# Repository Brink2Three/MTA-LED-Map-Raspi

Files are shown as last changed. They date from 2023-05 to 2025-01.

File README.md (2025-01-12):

# MTA-LED-Map-Raspi

## IN PROGRESS

A single python file that will pull NYC-MTA GTFS data and assign it to individually addressable LEDs. May also include NJ PATH data if I ever figure out how to parse their API.

## To make this yourself

### Parts

- Raspberry Pi (I have tested with a Zero1 W and a Zero 2 W)
- a 5V 8A Power supply (Enough to power the entire board you connect)
- Dupont connectors (for connecting power supply to board/Raspi for now)
- A board, ordered from JCLPCB, PCBway or any PCB order vendor. (see Maps/PCB Gerber Files)

### Software Steps

Install python3. This was tested on windows 10 22H2 with Python 3.10 and on a raspberry Pi Zero2 with Python 3.9.2.
Only the requests testing will work on windows, as the LED code will attempt to connect to non-existent GPIO pins.
//TODO Make "test display" via console to display labeled stops with LED colors.

Install the following dependancies as root. As far as I know, you cannot install them in a virtual environment. They need root access to use the GPIO pins.

```bash
sudo pip install rpi_ws281x
sudo pip install adafruit-circuitpython-neopixel
sudo python3 -m pip install --force-reinstall adafruit-blinka
sudo pip install time
sudo pip install datetime
sudo pip install nyct_gtfs
```

(python-dotenv used to be required, but nyct_gtfs no longer requires API keys!)

You can ignore warnings about any scripts not being in PATH.

Clone this repo to the raspberry pi, running raspbian 11 (raspberry piOS lite) or ubuntu server. The exact version I am running is `Raspbian GNU/Linux 11 (bullseye)`

Depending on what boards you have connected, run the related "displaymode.py" script.
*THIS WILL TAKE A MINUTE TO UPDATE.*
The raspberry pi Zero 1 is SLOW to read the SD card, and takes about 45-75 seconds per cycle.
The Pi Zero 2 is faster, averaging about 15-18 seconds per cycle for the bothalf-displaymode file.

If you get lights, you did it! You can now add the script to crontab to have it run on an interval. I suggest once every 2 minutes, as slow internet or SD cards can cause the runtime to go over 1 minute.

## EXPIERMENTAL

In the setup folder, there is a script that moves the nyct-gtfs folder to a ramdisk (from the default sudo install location). This is meant to decrease the wear and load time of the package, since it polls files in this directory 44 times per run for just the bothalf displaymode script. The plan is eventually to have all of this run persistently, but for now I just run it on startup and put the bothalf displaymode script in root's crontab to run it once every 2 minutes.

If you do not clear this before rebooting the pi, it *will* break. If it does, run `sudo pip install nyct_gtfs --force-reinstall`.
Example of error message:
```bash
Traceback (most recent call last):
  File "/home/brink/MTA-LED-Map-Raspi/mtaled-bothalf-displaymode.py", line 9, in <module>
    from nyct_gtfs import NYCTFeed
ImportError: cannot import name 'NYCTFeed' from 'nyct_gtfs' (unknown location)
```

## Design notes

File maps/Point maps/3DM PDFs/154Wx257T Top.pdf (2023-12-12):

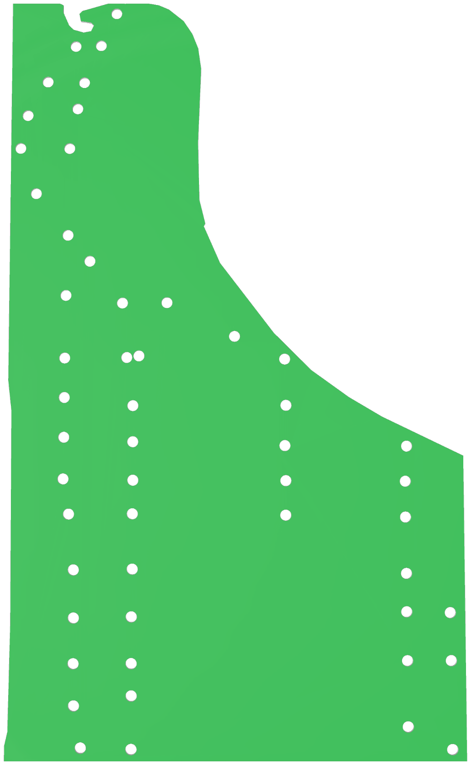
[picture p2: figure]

PCB SPLIT Manhattan map v5

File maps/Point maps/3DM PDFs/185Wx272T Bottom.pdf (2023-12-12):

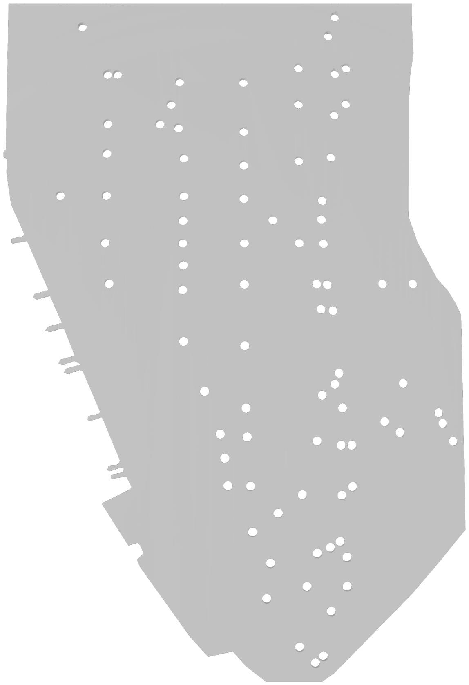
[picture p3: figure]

PCB SPLIT Manhattan map v4

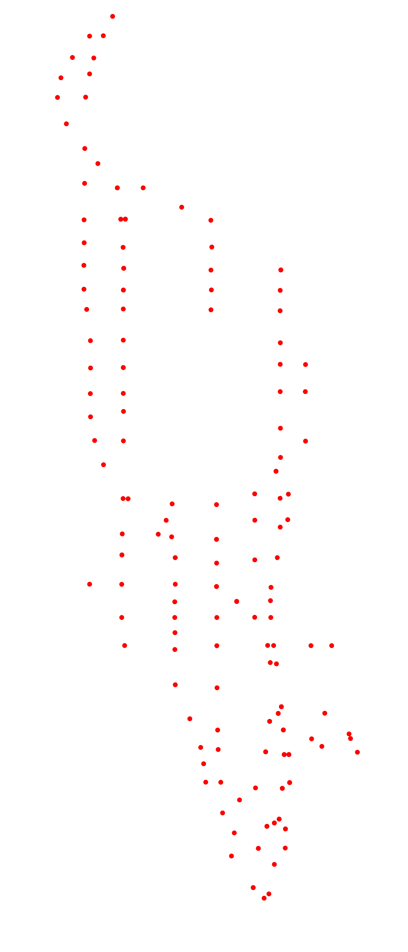
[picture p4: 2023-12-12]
maps/Points only-manhattanPCB.png

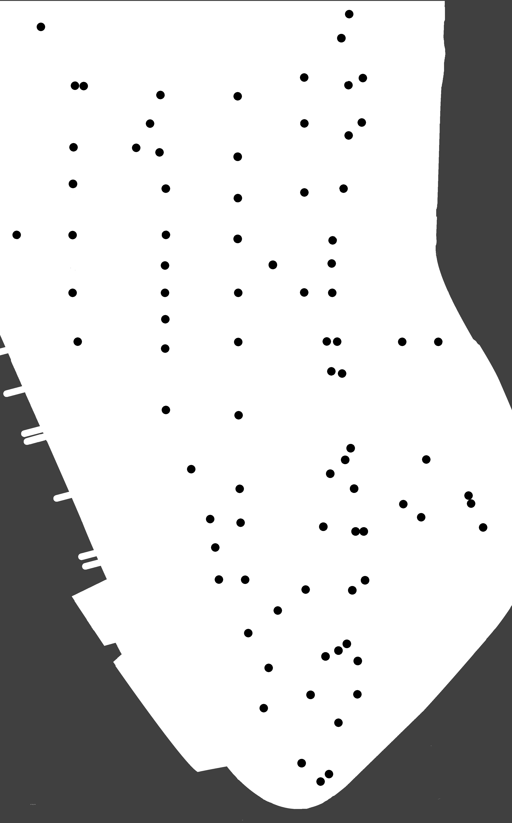
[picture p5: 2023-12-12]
maps/Point maps/Point reduced/Bottom Half image.png

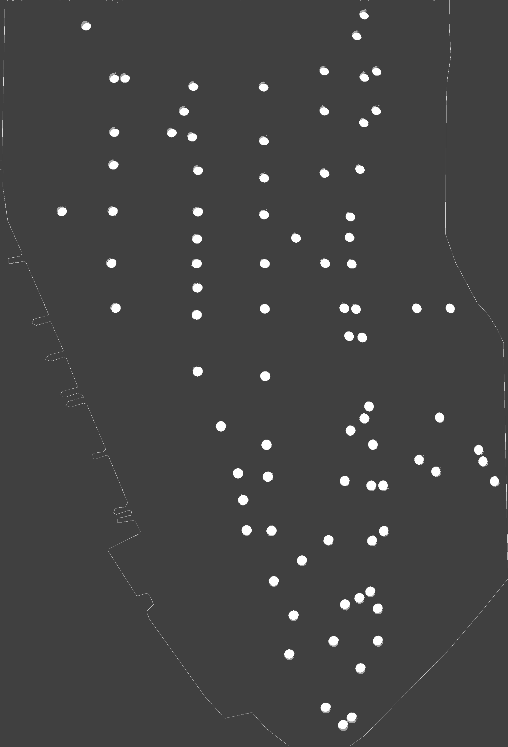
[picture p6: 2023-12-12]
maps/Point maps/3DM PDFs/185Wx272T Bottom.png

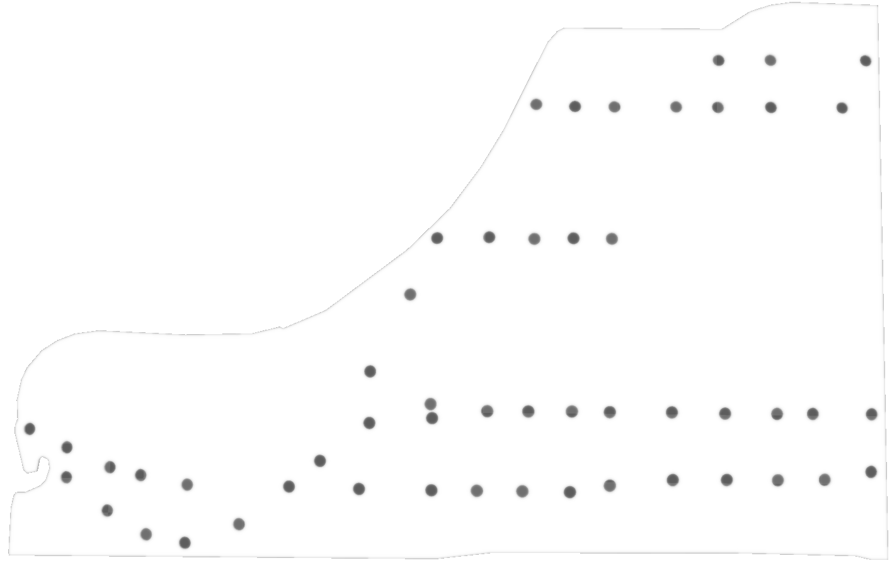
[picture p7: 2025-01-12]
maps/Point maps/Top of manhattan/Top-Manhattan-dots.png

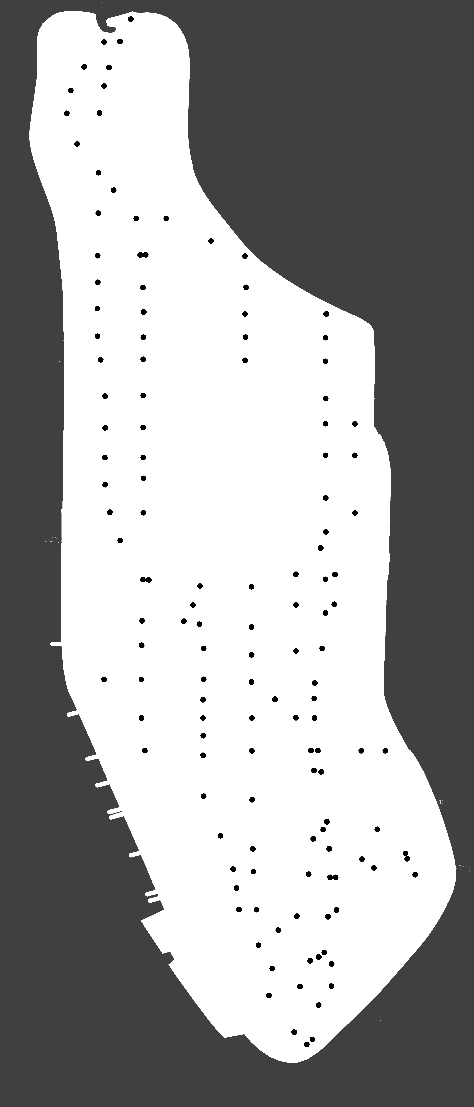
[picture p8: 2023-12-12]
maps/Subway Points only-manhattanV1.png

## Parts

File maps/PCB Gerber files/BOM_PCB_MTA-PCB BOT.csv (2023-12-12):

ID | Name | Designator | Footprint | Quantity | Manufacturer Part | Manufacturer | Supplier | Supplier Part | Price
1 | WS2812B-MINI | LED63,LED64,LED1,LED2,LED3,LED4,LED5,LED6,LED7,LED8,LED9,LED10,LED11,LED12,LED13,LED14,LED15,LED16,LED17,LED18,LED19,LED20,LED21,LED22,LED23,LED24,LED25,LED26,LED27,LED28,LED29,LED30,LED31,LED32,LED33,LED34,LED35,LED36,LED37,LED38,LED39,LED40,LED41,LED42,LED43,LED44,LED45,LED46,LED47,LED48,LED49,LED50,LED51,LED52,LED53,LED54,LED55,LED56,LED57,LED58,LED59,LED60,LED61,LED62,LED65,LED66,LED67,LED68,LED69,LED70,LED71,LED72,LED73,LED74,LED75,LED76,LED77,LED78,LED79,LED80,LED81,LED82,LED83,LED84,LED85 | LED-SMD_4P-L3.5-W3.5-TL_WS2812B | 85 | WS2812B-Mini | worldsemi | LCSC | C527089 | 0.099
2 | Header-Male-2.54_1x3 | H1,H2 | HDR-TH_3P-P2.54-V-M-1 | 2 | 2.54-1*3P针 | BOOMELE(博穆精密) | LCSC | C49257 | 0.015

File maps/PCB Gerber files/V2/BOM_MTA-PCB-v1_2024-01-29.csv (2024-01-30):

ID | Name | Designator | Footprint | Quantity | Manufacturer Part | Manufacturer | Supplier | Supplier Part | Price | Pins | 3DModel | Contributor | JLCPCB Part Class | link
1 | Header-Male-2.54_1x3 | H1,H2 | HDR-TH_3P-P2.54-V-M-1 | 2 | 2.54-1*3P针 | BOOMELE(博穆精密) | LCSC | C49257 | 0.015 | 3 | HDR-M-2.54_1x3 | lcsc | Extended Part | https://lcsc.com/eda_search?q=C49257&%26type=1&ref=editor
2 | WS2812B-MINI | LED1,LED2,LED3,LED4,LED5,LED6,LED7,LED8,LED9,LED10,LED11,LED12,LED13,LED14,LED15,LED16,LED17,LED18,LED19,LED20,LED21,LED22,LED23,LED24,LED25,LED26,LED27,LED28,LED29,LED30,LED31,LED32,LED33,LED34,LED35,LED36,LED37,LED38,LED39,LED40,LED41,LED42,LED43,LED44,LED45,LED46,LED47,LED48,LED49,LED50,LED51,LED52,LED53,LED54,LED55,LED56,LED57,LED58,LED59,LED60,LED61,LED62,LED63,LED64,LED65,LED66,LED67,LED68,LED69,LED70,LED71,LED72,LED73,LED74,LED75,LED76,LED77,LED78,LED79,LED80,LED81,LED82,LED83,LED84,LED85,LED86,LED87 | LED-SMD_4P-L3.5-W3.5-TL_WS2812B | 87 | WS2812B-Mini | worldsemi | LCSC | C527089 | 0.101 | 4 | LED3535-4P_L3.5-W3.5-H1.9-LS3.7 | LCSC | Extended Part | https://lcsc.com/eda_search?q=C527089&%26type=1&ref=editor

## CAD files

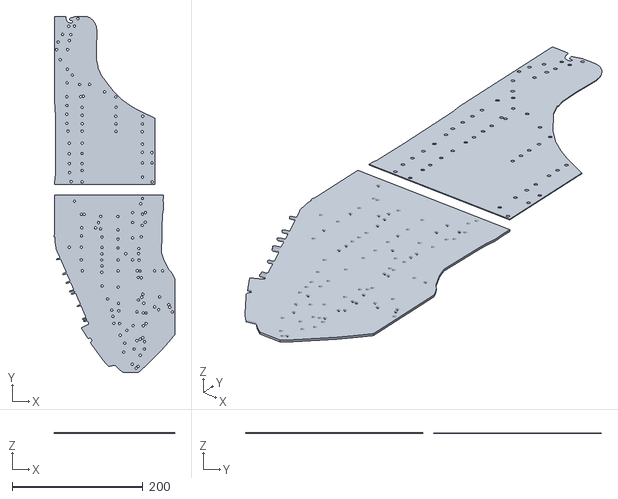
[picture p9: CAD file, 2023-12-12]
maps/Point maps/Point reduced/PCB SPLIT Manhattan map v5.stl
185.0 x 544.8 x 2.00

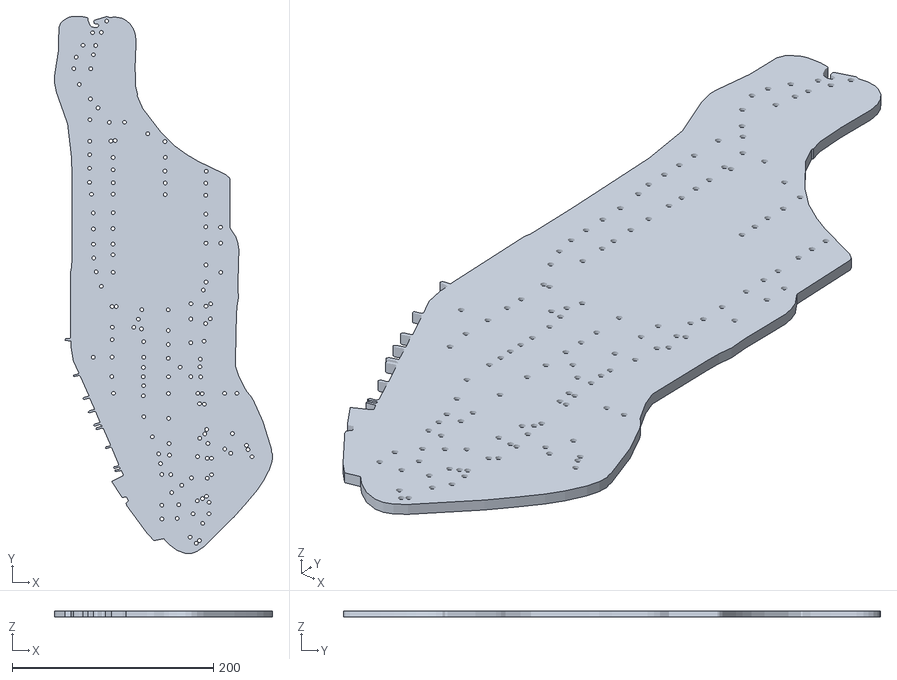
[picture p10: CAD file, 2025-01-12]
maps/Point maps/Top of manhattan/Manhattan v3.stl
216.9 x 533.4 x 6.35

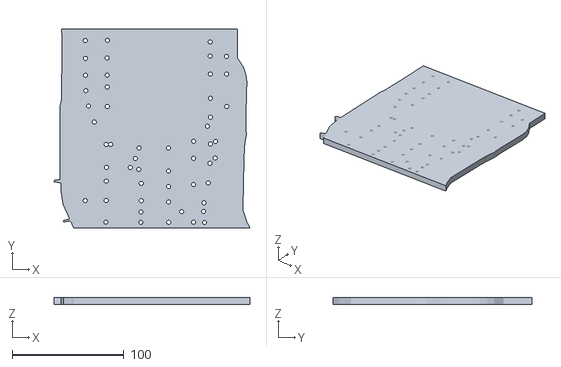
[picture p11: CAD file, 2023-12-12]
maps/Point maps/v4Manhattan MIDDLE.stl
175.5 x 178.4 x 6.35

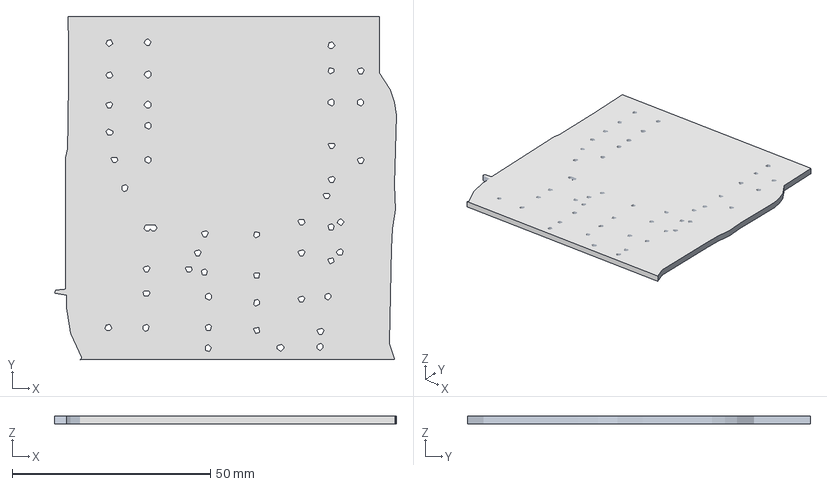
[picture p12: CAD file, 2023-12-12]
maps/Point maps/Subway Points only-manhattan part2.3mf
86.4 x 86.7 x 2.00 mm

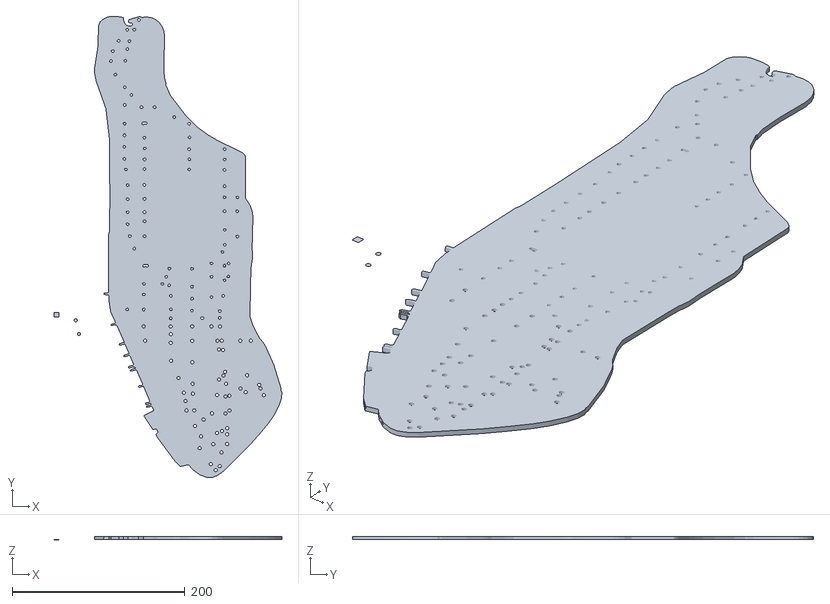
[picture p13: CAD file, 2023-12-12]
maps/Point maps/In progress Manhattan map.stl
263.7 x 533.4 x 3.59

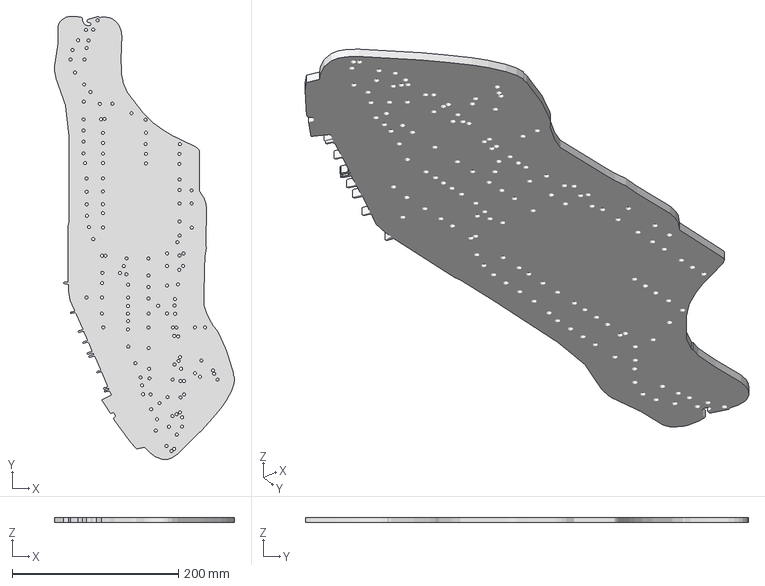
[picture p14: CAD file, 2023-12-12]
maps/Point maps/Point reduced/Manhattan map v4.3mf
216.9 x 533.4 x 5.68 mm

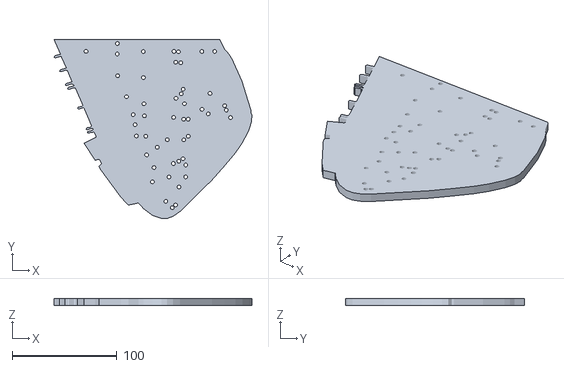
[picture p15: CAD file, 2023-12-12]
maps/Point maps/Point reduced/v4Manhattan BOTTOM.obj
188.6 x 170.4 x 6.35

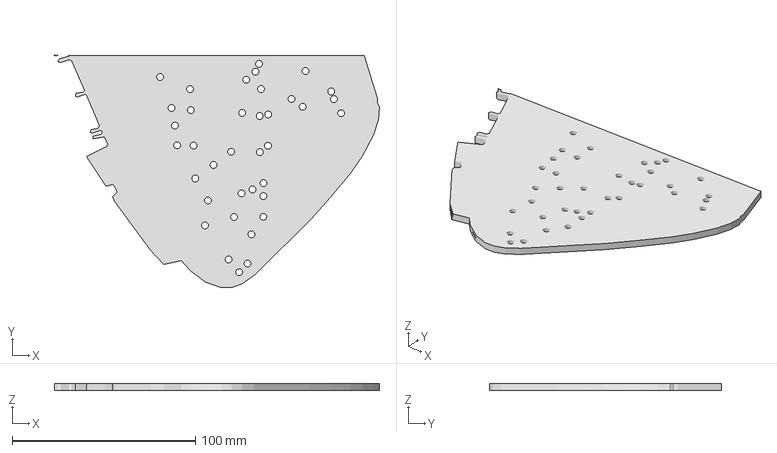
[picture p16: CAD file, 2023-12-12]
maps/Point maps/In progress Manhattan map( resized holes and inserts for LED outer).stl.3mf
177.5 x 126.9 x 3.59 mm

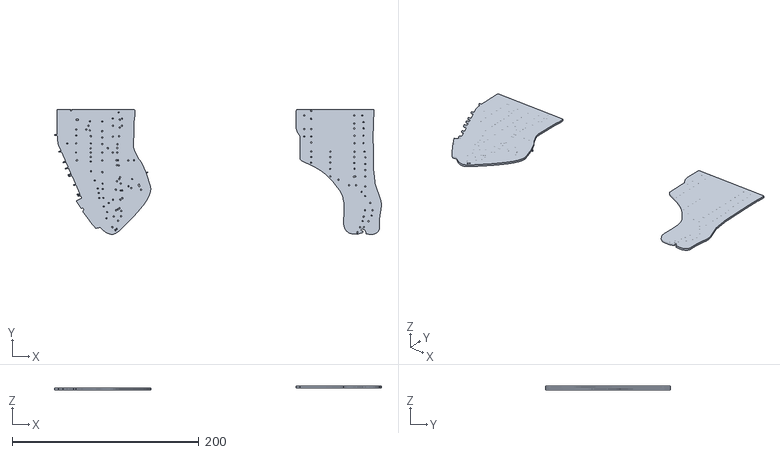
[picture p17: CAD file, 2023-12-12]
maps/Point maps/Subway Points only-manhattanV1.stl
349.9 x 133.4 x 4.00

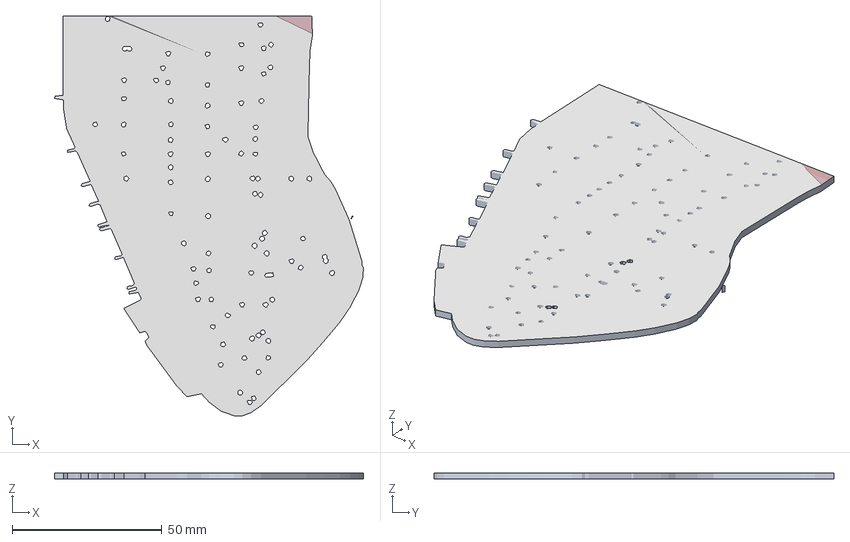
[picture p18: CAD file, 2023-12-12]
maps/Point maps/Subway Points only-manhattan bottom half.3mf
103.1 x 133.4 x 2.00 mm

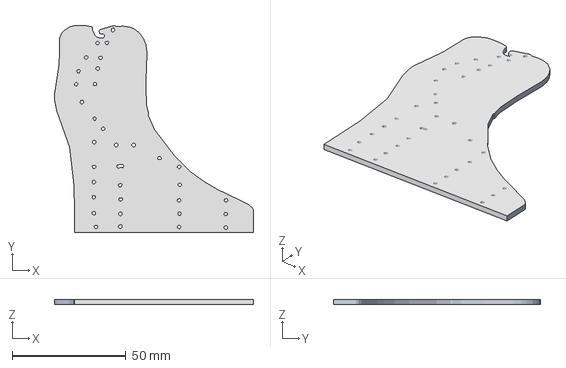
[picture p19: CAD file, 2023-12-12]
maps/Point maps/Subway Points only-manhattan part3.3mf
87.4 x 90.9 x 2.00 mm

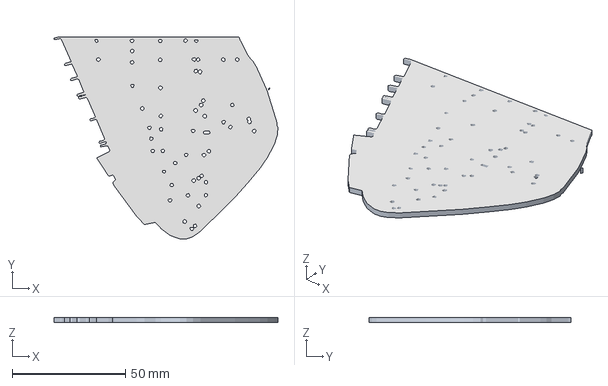
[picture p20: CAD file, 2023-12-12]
maps/Point maps/Subway Points only-manhattan part1.3mf
98.8 x 89.1 x 2.00 mm

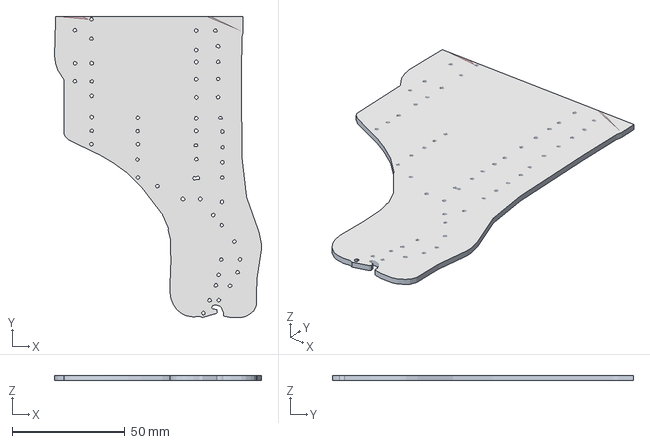
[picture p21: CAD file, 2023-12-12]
maps/Point maps/Subway Points only-manhattan top half.3mf
91.7 x 133.3 x 2.00 mm

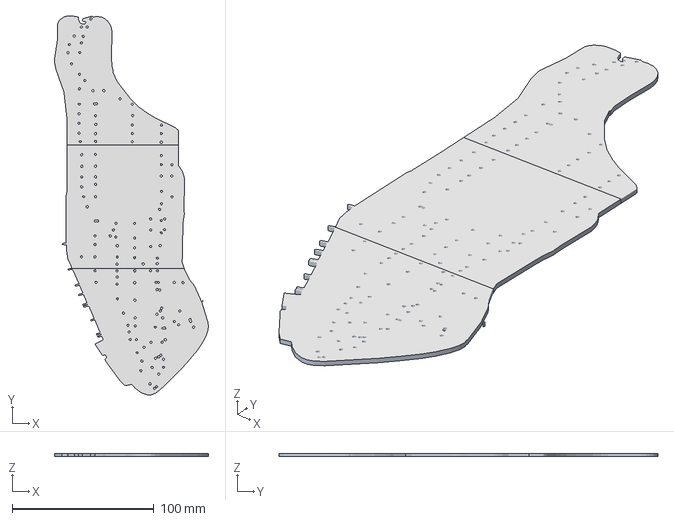
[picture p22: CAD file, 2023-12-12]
maps/Point maps/Subway Points only-manhattan split 3 parts.3mf
108.5 x 266.7 x 2.00 mm

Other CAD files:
maps/Point maps/Manhattan map v4.stl
maps/Point maps/Point reduced/v4Manhattan MIDDLE.3mf
maps/Point maps/Manhattan map part 1 v2.stl
maps/Point maps/v4Manhattan BOTTOM.stl
maps/Point maps/In progress Manhattan map v2.skp
maps/Point maps/In progress Manhattan map v3.skp
maps/Point maps/In progress Manhattan map.skp
maps/Point maps/Manhattan map v3.stl
maps/Point maps/Manhattan map v4.skp
maps/Point maps/Point reduced/Manhattan map v4.stl
maps/Point maps/Point reduced/PCB SPLIT Manhattan map v4.stl
maps/Point maps/Subway Points only-manhattan bottom half.stl
maps/Point maps/Subway Points only-manhattan part1.stl
maps/Point maps/Subway Points only-manhattan part2.stl
maps/Point maps/Subway Points only-manhattan part3.stl
maps/Point maps/Subway Points only-manhattan top half.stl
maps/Point maps/v4Manhattan TOP.stl

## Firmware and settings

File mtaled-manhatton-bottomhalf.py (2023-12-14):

#Combined project, once all parts are complete.
import time
import board
import neopixel
import os
from datetime import datetime, timedelta
from nyct_gtfs import NYCTFeed
from dotenv import load_dotenv
load_dotenv()

MTA_API_KEY = os.getenv('api_key')


#NEOPIXEL SETTINGS MUST BE SET BELOW
#pixels1 = neopixel.NeoPixel(board.D18, 87, brightness=.15)
# Line colors so I don't have to type the codes out
line_123 = (127, 0, 0)
line_456 = (0, 127, 7)
line_7 = (100, 0, 100)
line_ace = (6, 20, 127)
line_bdfm = (255, 107, 0)
line_jz = (190, 50, 14)
line_nqrw = (252, 204, 10)
line_ls = (128, 129, 131)
line_g = (0, 127, 7)
line_h = (11, 11, 11)
bg = (5, 5, 5)

lines = ["1", "2", "3", "4", "5", "6", "7", "A", "C", "E", "B", "D", "F", "M", "N", "Q", "R", "W", "J", "Z", "L", "S"]
brokenstops = ["R70N", "R70S", "R60S", "R60N", "R65S", "R65N", "D23S", "D23N", "H17S", "H18S", "A29S"]
lines_array = []
stops_array = []
combined_array = []

def process_lines(line_num):
    processed_lines = line_num
    return processed_lines

# print the feed line by line
def main():
    for line_num in lines:
        line_id = process_lines(line_num)
        line = [line_id]
        feed = NYCTFeed(line_id, api_key=MTA_API_KEY)
        print_feed(feed, line)

def print_feed(feed, line_id):
    for trip in feed.filter_trips(line_id):
        if trip.location in brokenstops:
            pass
        else:
            stop_check = str(trip)
            if stop_check.__contains__("STOPPED_AT"):
                lines_array.append(stop_check[11:12])
                stop_ind = stop_check.find('STOPPED_AT') + len('STOPPED_AT ')
                last_ind = stop_check.find(', last update')
                stops_array.append(stop_check[stop_ind:last_ind])
                #print(stop_check[11:12] + " " + stop_check[stop_ind:last_ind])
            else:
                pass

if __name__ == '__main__':
    main()
    for i in range(len(lines_array)): 
        combined_array.append(str(lines_array[i] + " " + stops_array[i]))
    print(combined_array)
    #set all pixels to white
    pixels1 = neopixel.NeoPixel(board.D18, 87, brightness=.15)
    pixels1.fill((15, 15, 15))
    ###### 1 Line ##########
    if "1 66 St-Lincoln Center" in combined_array:
        pixels1[84]= line_123
    else:
        pass
    if "1 59 St-Columbus Circle" in combined_array:
        pixels1[82]= line_123
    else:
        pass
    if "1 50 St" in combined_array:
        pixels1[70]= line_123
    else:
        pass
    if "1 Times Sq-42 St" in combined_array:
        pixels1[67]= line_123
    else:
        pass
    if "1 34 St-Penn Station" in combined_array:
        pixels1[61]= line_123
    else:
        pass
    if "1 28 St" in combined_array:
        pixels1[58]= line_123
    else:
        pass
    if "1 23 St" in combined_array:
        pixels1[52]= line_123
    else:
        pass
    if "1 18 St" in combined_array:
        pixels1[50]= line_123
    else:
        pass
    if "1 14 St" in combined_array:
        pixels1[48]= line_123
    else:
        pass
    if "1 Christopher St-Sheridan Sq" in combined_array:
        pixels1[40]= line_123
    else:
        pass
    if "1 Houston St" in combined_array:
        pixels1[34]= line_123
    else:
        pass
    if "1 Canal St" in combined_array:
        pixels1[22]= line_123
    else:
        pass
    if "1 Franklin St" in combined_array:
        pixels1[21]= line_123
    else:
        pass
    if "1 Chambers St" in combined_array:
        pixels1[19]= line_123
    else:
        pass
    if "1 WTC Cortlandt" in combined_array:
        pixels1[0]= line_123
    else:
        pass
    if "1 Rector St" in combined_array:
        pixels1[5]= line_123
    else:
        pass
    if "1 South Ferry Loop" in combined_array:
        pixels1[2]= line_123
    else:
        pass
    if "1 South Ferry" in combined_array:
        pixels1[2]= line_123
    else:
        pass
    ###### 2 Line #######
    if "2 Park Place" in combined_array:
        pixels1[64]= line_123
    else:
        pass
    if "2 Fulton St" in combined_array:
        pixels1[65]= line_123
    else:
        pass
    if "2 Wall St" in combined_array:
        pixels1[4]= line_123
    else:
        pass
    ##### 4 Line ######
    if "4 Fulton St" in combined_array:
        pixels1[10]= line_456
    else:
        pass
    if "4 Wall St" in combined_array:
        pixels1[7]= line_456
    else:
        pass
    if "4 Bowling Green" in combined_array:
        pixels1[4]= line_456
    else:
        pass
##### 6 Line #####
    if "6 68 St-Hunter College" in combined_array:
        pixels1[86]= line_456
    else:
        pass
    if "6 59 St" in combined_array:
        pixels1[77]= line_456
    else:
        pass
    if "6 51 St" in combined_array:
        pixels1[74]= line_456
    else:
        pass
    if "6 Grand Central-42 St" in combined_array:
        pixels1[64]= line_456
    else:
        pass
    if "6 33 St" in combined_array:
        pixels1[63]= line_456
    else:
        pass
    if "6 28 St" in combined_array:
        pixels1[56]= line_456
    else:
        pass
    if "6 23 St" in combined_array:
        pixels1[54]= line_456
    else:
        pass
    if "6 14 St-Union Sq" in combined_array:
        pixels1[45]= line_456
    else:
        pass
    if "6 Astor Pl" in combined_array:
        pixels1[42]= line_456
    else:
        pass
    if "6 Bleecker St" in combined_array:
        pixels1[37]= line_456
    else:
        pass
    if "6 Spring St" in combined_array:
        pixels1[32]= line_456
    else:
        pass
    if "6 Canal St" in combined_array:
        pixels1[25]= line_456
    else:
        pass
    if "6 Brooklyn Bridge-City Hall" in combined_array:
        pixels1[17]= line_456
    else:
        pass
##### 7 Line #####   
    if "7 Grand Central-42 St" in combined_array:
        pixels1[64]= line_7
    else:
        pass
    if "7 5 Av" in combined_array:
        pixels1[65]= line_7
    else:
        pass
    if "7 Times Sq-42 St" in combined_array:
        pixels1[67]= line_7
    else:
        pass
    if "7 34 St-Hudson Yards" in combined_array:
        pixels1[59]= line_7
    else:
        pass
##### S line (Times-GCS Shuttle) #####    
    if "S Grand Central-42 St" in combined_array:
        pixels1[64]= line_ls
    else:
        pass
    if "S Times Sq-42 St" in combined_array:
        pixels1[67]= line_ls
    else:
        pass
##### A Line #####
    if "A 59 St-Columbus Circle" in combined_array:
        pixels1[83]= line_ace
    else:
        pass
    if "A 50 St" in combined_array:
        pixels1[69]= line_ace
    else:
        pass
    if "A 42 St-Port Authority Bus Terminal" in combined_array:
        pixels1[68]= line_ace
    else:
        pass
    if "A 34 St-Penn Station" in combined_array:
        pixels1[60]= line_ace
    else:
        pass
    if "A 23 St" in combined_array:
        pixels1[51]= line_ace
    else:
        pass
    if "A 14 St" in combined_array:
        pixels1[49]= line_ace
    else:
        pass
    if "A W 4 St-Wash Sq" in combined_array:
        pixels1[39]= line_ace
    else:
        pass
    if "A Spring St" in combined_array:
        pixels1[33]= line_ace
    else:
        pass
    if "A Canal St" in combined_array:
        pixels1[23]= line_ace
    else:
        pass
    if "A Chambers St" in combined_array:
        pixels1[20]= line_ace
    else:
        pass
    if "A Fulton St" in combined_array:
        pixels1[11]= line_ace
    else:
        pass
##### E Line #####
    if "E World Trade Center" in combined_array:
        pixels1[14]= line_ace
    else:
        pass
##### B Line
    if "B Lexington Av/63 St" in combined_array:
        pixels1[84]= line_bdfm
    else:
        pass
    if "B 57 St" in combined_array:
        pixels1[79]= line_bdfm
    else:
        pass
##### D Line 
    if "D 7 Av" in combined_array:
        pixels1[80]= line_bdfm
    else:
        pass
    if "D 47-50 Sts-Rockefeller Ctr" in combined_array:
        pixels1[72]= line_bdfm
    else:
        pass
    if "D 42 St-Bryant Pk" in combined_array:
        pixels1[66]= line_bdfm
    else:
        pass
    if "D 34 St-Herald Sq" in combined_array:
        pixels1[62]= line_bdfm
    else:
        pass
    if "D 23 St" in combined_array:
        pixels1[53]= line_bdfm
    else:
        pass
    if "D 14 St" in combined_array:
        pixels1[47]= line_bdfm
    else:
        pass
    if "D W 4 St-Wash Sq" in combined_array:
        pixels1[39]= line_bdfm
    else:
        pass
    if "D Broadway-Lafayette St" in combined_array:
        pixels1[36]= line_bdfm
    else:
        pass
    if "D Grand St" in combined_array:
        pixels1[27]= line_bdfm
    else:
        pass
##### F Line #####
    if "F Lexington Av/53 St" in combined_array:
        pixels1[75]= line_bdfm
    else:
        pass
    if "F 5 Av/53 St" in combined_array:
        pixels1[73]= line_bdfm
    else:
        pass
    if "F 2 Av" in combined_array:
        pixels1[38]= line_bdfm
    else:
        pass
    if "F Delancey St-Essex St" in combined_array:
        pixels1[30]= line_bdfm
    else:
        pass
    if "F East Broadway" in combined_array:
        pixels1[28]= line_bdfm
    else:
        pass
##### J or Z trains labeled as their old M stops #####
    if "M Delancey St-Essex St" in combined_array:
        pixels1[29]= line_bdfm
    else:
        pass
    if "M Bowery" in combined_array:
        pixels1[31]= line_bdfm
    else:
        pass
    if "M Canal St" in combined_array:
        pixels1[26]= line_bdfm
    else:
        pass
    if "M Chambers St" in combined_array:
        pixels1[18]= line_bdfm
    else:
        pass
    if "M Fulton St" in combined_array:
        pixels1[12]= line_bdfm
    else:
        pass
    if "M Broad St" in combined_array:
        pixels1[5]= line_bdfm
    else:
        pass
##### J Line #####
# None in manhattan

##### L Line #####
    if "L 8 Av" in combined_array:
        pixels1[49]= line_ls
    else:
        pass
    if "L 6 Av" in combined_array:
        pixels1[47]= line_ls
    else:
        pass
    if "L 14 St-Union Sq" in combined_array:
        pixels1[45]= line_ls
    else:
        pass
    if "L 3 Av" in combined_array:
        pixels1[44]= line_ls
    else:
        pass
    if "L 1 Av" in combined_array:
        pixels1[43]= line_ls
    else:
        pass
##### N Line #####    
## None in Manhattan

##### Q Line #####
    if "Q Canal St" in combined_array:
        pixels1[24]= line_nqrw
    else:
        pass
##### R Line #####
    if "R Lexington Av/59 St" in combined_array:
        pixels1[76]= line_nqrw
    else:
        pass
    if "R 5 Av/59 St" in combined_array:
        pixels1[78]= line_nqrw
    else:
        pass
    if "R 57 St-7 Av" in combined_array:
        pixels1[81]= line_nqrw
    else:
        pass
    if "R 49 St" in combined_array:
        pixels1[71]= line_nqrw
    else:
        pass
    if "R Times Sq-42 St" in combined_array:
        pixels1[67]= line_nqrw
    else:
        pass
    if "R 34 St-Herald Sq" in combined_array:
        pixels1[62]= line_nqrw
    else:
        pass
    if "R 28 St" in combined_array:
        pixels1[57]= line_nqrw
    else:
        pass
    if "R 23 St" in combined_array:
        pixels1[54]= line_nqrw
    else:
        pass
    if "R 14 St-Union Sq" in combined_array:
        pixels1[46]= line_nqrw
    else:
        pass
    if "R 8 St-NYU" in combined_array:
        pixels1[41]= line_nqrw
    else:
        pass
    if "R Prince St" in combined_array:
        pixels1[35]= line_nqrw
    else:
        pass
    if "R Canal St" in combined_array:
        pixels1[24]= line_nqrw
    else:
        pass
    if "R City Hall" in combined_array:
        pixels1[16]= line_nqrw
    else:
        pass
    if "R Cortlandt St" in combined_array:
        pixels1[9]= line_nqrw
    else:
        pass
    if "R Rector St" in combined_array:
        pixels1[6]= line_nqrw
    else:
        pass
    if "R Whitehall St-South Ferry" in combined_array:
        pixels1[3]= line_nqrw
    else:
##### SF Line #####
# None in Manhattan
        ()
    # temp while testing to not use extra power
    time.sleep(10)
    pixels1.fill((0, 0, 0))
    

else: 
    ()

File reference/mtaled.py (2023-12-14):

#Combined project, once all parts are complete.
import time
import board
import neopixel
import os
from datetime import datetime, timedelta
from nyct_gtfs import NYCTFeed
from dotenv import load_dotenv
load_dotenv()

MTA_API_KEY = os.getenv('api_key')


#NEOPIXEL SETTINGS MUST BE SET BELOW
#pixels1 = neopixel.NeoPixel(board.D18, 87, brightness=.15)
# Line colors so I don't have to type the codes out
#MTA SETTINGS
#possible_stops = ["1 Van Cortlandt Park-242 St" ,"1 238 St" ,"1 231 St" ,"1 Marble Hill-225 St" ,"1 215 St" ,"1 207 St" ,"1 Dyckman St" ,"1 191 St" ,"1 181 St" ,"1 168 St-Washington Hts" ,"1 157 St" ,"1 145 St" ,"1 137 St-City College" ,"1 125 St" ,"1 116 St-Columbia University" ,"1 Cathedral Pkwy (110 St)" ,"1 103 St" ,"1 96 St" ,"1 86 St" ,"1 79 St" ,"1 72 St" ,"1 66 St-Lincoln Center" ,"1 59 St-Columbus Circle" ,"1 50 St" ,"1 Times Sq-42 St" ,"1 34 St-Penn Station" ,"1 28 St" ,"1 23 St" ,"1 18 St" ,"1 14 St" ,"1 Christopher St-Sheridan Sq" ,"1 Houston St" ,"1 Canal St" ,"1 Franklin St" ,"1 Chambers St" ,"1 WTC Cortlandt" ,"1 Rector St" ,"1 South Ferry Loop" ,"1 South Ferry" ,"2 Wakefield-241 St" ,"2 Nereid Av" ,"2 233 St" ,"2 225 St" ,"2 219 St" ,"2 Gun Hill Rd" ,"2 Burke Av" ,"2 Allerton Av" ,"2 Pelham Pkwy" ,"2 Bronx Park East" ,"2 E 180 St" ,"2 West Farms Sq-E Tremont Av" ,"2 174 St" ,"2 Freeman St" ,"2 Simpson St" ,"2 Intervale Av" ,"2 Prospect Av" ,"2 Jackson Av" ,"2 3 Av-149 St" ,"2 149 St-Grand Concourse" ,"2 135 St" ,"2 125 St" ,"2 116 St" ,"2 Central Park North (110 St)" ,"2 Park Place" ,"2 Fulton St" ,"2 Wall St" ,"2 Clark St" ,"2 Borough Hall" ,"2 Hoyt St" ,"2 Nevins St" ,"2 Atlantic Av-Barclays Ctr" ,"2 Bergen St" ,"2 Grand Army Plaza" ,"2 Eastern Pkwy-Brooklyn Museum" ,"2 Franklin Av-Medgar Evers College" ,"2 President St-Medgar Evers College" ,"2 Sterling St" ,"2 Winthrop St" ,"2 Church Av" ,"2 Beverly Rd" ,"2 Newkirk Av-Little Haiti" ,"2 Flatbush Av-Brooklyn College" ,"2 Nostrand Av" ,"2 Kingston Av" ,"2 Crown Hts-Utica Av" ,"2 Sutter Av-Rutland Rd" ,"2 Saratoga Av" ,"2 Rockaway Av" ,"2 Junius St" ,"2 Pennsylvania Av" ,"2 Van Siclen Av" ,"2 New Lots Av" ,"3 Harlem-148 St" ,"3 145 St" ,"4 Woodlawn" ,"4 Mosholu Pkwy" ,"4 Bedford Park Blvd-Lehman College" ,"4 Kingsbridge Rd" ,"4 Fordham Rd" ,"4 183 St" ,"4 Burnside Av" ,"4 176 St" ,"4 Mt Eden Av" ,"4 170 St" ,"4 167 St" ,"4 161 St-Yankee Stadium" ,"4 149 St-Grand Concourse" ,"4 138 St-Grand Concourse" ,"4 Fulton St" ,"4 Wall St" ,"4 Bowling Green" ,"4 Borough Hall" ,"5 Eastchester-Dyre Av" ,"5 Baychester Av" ,"5 Gun Hill Rd" ,"5 Pelham Pkwy" ,"5 Morris Park" ,"6 Pelham Bay Park" ,"6 Buhre Av" ,"6 Middletown Rd" ,"6 Westchester Sq-E Tremont Av" ,"6 Zerega Av" ,"6 Castle Hill Av" ,"6 Parkchester" ,"6 St Lawrence Av" ,"6 Morrison Av-Soundview" ,"6 Elder Av" ,"6 Whitlock Av" ,"6 Hunts Point Av" ,"6 Longwood Av" ,"6 E 149 St" ,"6 E 143 St-St Mary's St" ,"6 Cypress Av" ,"6 Brook Av" ,"6 3 Av-138 St" ,"6 125 St" ,"6 116 St" ,"6 110 St" ,"6 103 St" ,"6 96 St" ,"6 86 St" ,"6 77 St" ,"6 68 St-Hunter College" ,"6 59 St" ,"6 51 St" ,"6 Grand Central-42 St" ,"6 33 St" ,"6 28 St" ,"6 23 St" ,"6 14 St-Union Sq" ,"6 Astor Pl" ,"6 Bleecker St" ,"6 Spring St" ,"6 Canal St" ,"6 Brooklyn Bridge-City Hall" ,"7 Flushing-Main St" ,"7 Mets-Willets Point" ,"7 111 St" ,"7 103 St-Corona Plaza" ,"7 Junction Blvd" ,"7 90 St-Elmhurst Av" ,"7 82 St-Jackson Hts" ,"7 74 St-Broadway" ,"7 69 St" ,"7 61 St-Woodside" ,"7 52 St" ,"7 46 St-Bliss St" ,"7 40 St-Lowery St" ,"7 33 St-Rawson St" ,"7 Queensboro Plaza" ,"7 Court Sq" ,"7 Hunters Point Av" ,"7 Vernon Blvd-Jackson Av" ,"7 Grand Central-42 St" ,"7 5 Av" ,"7 Times Sq-42 St" ,"7 34 St-Hudson Yards" ,"S Grand Central-42 St" ,"S Times Sq-42 St" ,"A Inwood-207 St" ,"A Dyckman St" ,"A 190 St" ,"A 181 St" ,"A 175 St" ,"A 168 St" ,"A 163 St-Amsterdam Av" ,"A 155 St" ,"A 145 St" ,"A 135 St" ,"A 125 St" ,"A 116 St" ,"A Cathedral Pkwy (110 St)" ,"A 103 St" ,"A 96 St" ,"A 86 St" ,"A 81 St-Museum of Natural History" ,"A 72 St" ,"A 59 St-Columbus Circle" ,"A 50 St" ,"A 42 St-Port Authority Bus Terminal" ,"A 34 St-Penn Station" ,"A 23 St" ,"A 14 St" ,"A W 4 St-Wash Sq" ,"A Spring St" ,"A Canal St" ,"A Chambers St" ,"A Fulton St" ,"A High St" ,"A Jay St-MetroTech" ,"A Hoyt-Schermerhorn Sts" ,"A Lafayette Av" ,"A Clinton-Washington Avs" ,"A Franklin Av" ,"A Nostrand Av" ,"A Kingston-Throop Avs" ,"A Utica Av" ,"A Ralph Av" ,"A Rockaway Av" ,"A Broadway Junction" ,"A Liberty Av" ,"A Van Siclen Av" ,"A Shepherd Av" ,"A Euclid Av" ,"A Grant Av" ,"A 80 St" ,"A 88 St" ,"A Rockaway Blvd" ,"A 104 St" ,"A 111 St" ,"A Ozone Park-Lefferts Blvd" ,"B 21 St-Queensbridge" ,"B Roosevelt Island" ,"B Lexington Av/63 St" ,"B 57 St" ,"B 9 Av" ,"B Fort Hamilton Pkwy" ,"B 50 St" ,"B 55 St" ,"B 62 St" ,"B 71 St" ,"B 79 St" ,"B 18 Av" ,"B 20 Av" ,"B Bay Pkwy" ,"B 25 Av" ,"B Bay 50 St" ,"D Norwood-205 St" ,"D Bedford Park Blvd" ,"D Kingsbridge Rd" ,"D Fordham Rd" ,"D 182-183 Sts" ,"D Tremont Av" ,"D 174-175 Sts" ,"D 170 St" ,"D 167 St" ,"D 161 St-Yankee Stadium" ,"D 155 St" ,"D 145 St" ,"D 7 Av" ,"D 47-50 Sts-Rockefeller Ctr" ,"D 42 St-Bryant Pk" ,"D 34 St-Herald Sq" ,"D 23 St" ,"D 14 St" ,"D W 4 St-Wash Sq" ,"D Broadway-Lafayette St" ,"D Grand St" ,"D Atlantic Av-Barclays Ctr" ,"D Prospect Park" ,"D Parkside Av" ,"D Church Av" ,"D Beverley Rd" ,"D Cortelyou Rd" ,"D Newkirk Plaza" ,"D Avenue H" ,"D Avenue J" ,"D Avenue M" ,"D Kings Hwy" ,"D Avenue U" ,"D Neck Rd" ,"D Sheepshead Bay" ,"D Brighton Beach" ,"D Ocean Pkwy" ,"D W 8 St-NY Aquarium" ,"D Coney Island-Stillwell Av" ,"E World Trade Center" ,"F Jamaica-179 St" ,"F 169 St" ,"F Parsons Blvd" ,"F Sutphin Blvd" ,"F Briarwood" ,"F Kew Gardens-Union Tpke" ,"F 75 Av" ,"F Court Sq-23 St" ,"F Lexington Av/53 St" ,"F 5 Av/53 St" ,"F 2 Av" ,"F Delancey St-Essex St" ,"F East Broadway" ,"F York St" ,"F Bergen St" ,"F Carroll St" ,"F Smith-9 Sts" ,"F 4 Av-9 St" ,"F 7 Av" ,"F 15 St-Prospect Park" ,"F Fort Hamilton Pkwy" ,"F Church Av" ,"F Ditmas Av" ,"F 18 Av" ,"F Avenue I" ,"F Bay Pkwy" ,"F Avenue N" ,"F Avenue P" ,"F Kings Hwy" ,"F Avenue U" ,"F Avenue X" ,"F Neptune Av" ,"G Jamaica Center-Parsons/Archer" ,"G Sutphin Blvd-Archer Av-JFK Airport" ,"G Jamaica-Van Wyck" ,"G Forest Hills-71 Av" ,"G 67 Av" ,"G 63 Dr-Rego Park" ,"G Woodhaven Blvd" ,"G Grand Av-Newtown" ,"G Elmhurst Av" ,"G Jackson Hts-Roosevelt Av" ,"G 65 St" ,"G Northern Blvd" ,"G 46 St" ,"G Steinway St" ,"G 36 St" ,"G Queens Plaza" ,"G Court Sq" ,"G 21 St" ,"G Greenpoint Av" ,"G Nassau Av" ,"G Metropolitan Av" ,"G Broadway" ,"G Flushing Av" ,"G Myrtle-Willoughby Avs" ,"G Bedford-Nostrand Avs" ,"G Classon Av" ,"G Clinton-Washington Avs" ,"G Fulton St" ,"H Aqueduct Racetrack" ,"H Aqueduct-N Conduit Av" ,"H Howard Beach-JFK Airport" ,"H Broad Channel" ,"H Beach 67 St" ,"H Beach 60 St" ,"H Beach 44 St" ,"H Beach 36 St" ,"H Beach 25 St" ,"H Far Rockaway-Mott Av" ,"H Beach 90 St" ,"H Beach 98 St" ,"H Beach 105 St" ,"H Rockaway Park-Beach 116 St" ,"J 121 St" ,"J 111 St" ,"J 104 St" ,"J Woodhaven Blvd" ,"J 85
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

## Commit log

2023-04-30 Fix print text to not repeat. Added end segment to show all colors side by side
    [colortest.py]
2023-04-30 Fix bdfm and jz take 2
    [colortest.py]
2023-04-30 Fix formatting error when printing stopped trains
    [MTA-api-requests-test v2.py]
2023-04-30 Remove direction variable from print_feed to print more train data from less code
2023-05-07 stage vars for line and stop to assign to leds
2023-05-07 Add two more stops to brokenstops array... Create blank arrays for lines and stops
    [mtaled.py]
2023-05-13 combine line and stop to one string in array for LED match purposes
2023-05-14 change line references to match possible stops array
    [Line-Number-Stop-List-Unduplicated-rows.csv, Line-Number-Stop-List-Unduplicated.csv]
2023-06-27 Test dumb elif strings for stop lighting
    [Subway Points only-manhattan bottom half.3mf, Subway Points only-manhattan bottom half.stl, Subway Points only-manhattan part1.3mf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]
2023-06-27 assigned LED stops take 2.
2023-06-27 turn off all LEDs when script ends (temp)
2023-06-27 Forgot to correct trailing else, gave file correct extension.
    [indexing test.py]
2023-12-03 In progress map files. This includes the 3d print files for the overlay and the gerber files for the underlying circuitboard.
    [BOM_PCB_MTA-PCB BOT.csv, In progress Manhattan map v2.skp, In progress Manhattan map v3.skp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]
2023-12-12 Test station alignments. LED 1 on board equals pixel 0
2023-12-14 change LED count to match fixed PCB
    [OneStripNeopixel.py, colortest.py, indexing test.py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]
2023-12-14 Adjusting for 2 LED offset in references
2023-12-14 it's late and I did math wrong
    [stationtest.py]
2023-12-14 debugging invalid API key error
    [MTA-api-requests-test v2.py, mtaled-bottomhalf-debug.py, mtaledv2-test-line1.py]
2023-12-14 displaymode in testing with bottom half board
2023-12-17 correct LED numbers for 2 line Fulton and Park place stops
    [mtaled-bothalf-displaymode.py, mtaled-bottomhalf-debug.py]
2023-12-17 correct trains to use new labels for J or Z lines
    [mtaled-bothalf-displaymode.py]
2024-01-30 move files around, update readme, update gerber/Pick-n-Place files to include all 87 LEDs in bottomhalf of manhattan
    [BOM_MTA-PCB-v1_2024-01-29.csv, PickAndPlace_PCB_MTA-PCB-v2_2024-01-29.csv]
2025-01-12 updated version of displaymode file to use a key-value map instead of if/else statements
    [Manhattan v3.stl]
